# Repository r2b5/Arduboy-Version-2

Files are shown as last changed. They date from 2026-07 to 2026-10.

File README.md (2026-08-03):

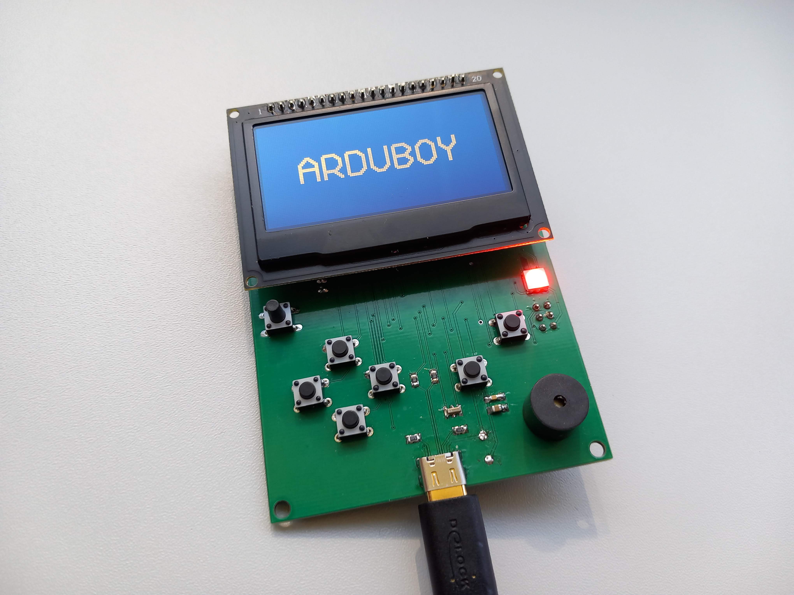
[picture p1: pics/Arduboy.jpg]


# Arduboy Version 2

Arduboy Version 2 is a custom-built handheld game console based on the original **DIY Mini Retro Game Console** by **MaDDy Regal** (Uttar Pradesh, India), published on Instructables.

Unlike the original design, this version integrates the Arduino Nano's **ATmega32U4** microcontroller directly onto a custom PCB. It also features a USB Type-C connector for power and programming, an integrated Li-ion battery charging circuit, and a larger OLED display.

## Hardware

- **Microcontroller:** ATmega32U4-AU
- **Display:** 2.42" 128×64 SPI OLED (Joy-it COM-OLED2.42, SSD1309 controller)
- Integrated Li-ion battery charging circuit MCP73831
- Custom-designed PCB

## Software

- Arduino IDE
- CadSoft Eagle

> **Note:**  
> The game source code is **not my own work**. It consists of example projects that have been adapted to run on this hardware implementation.
>
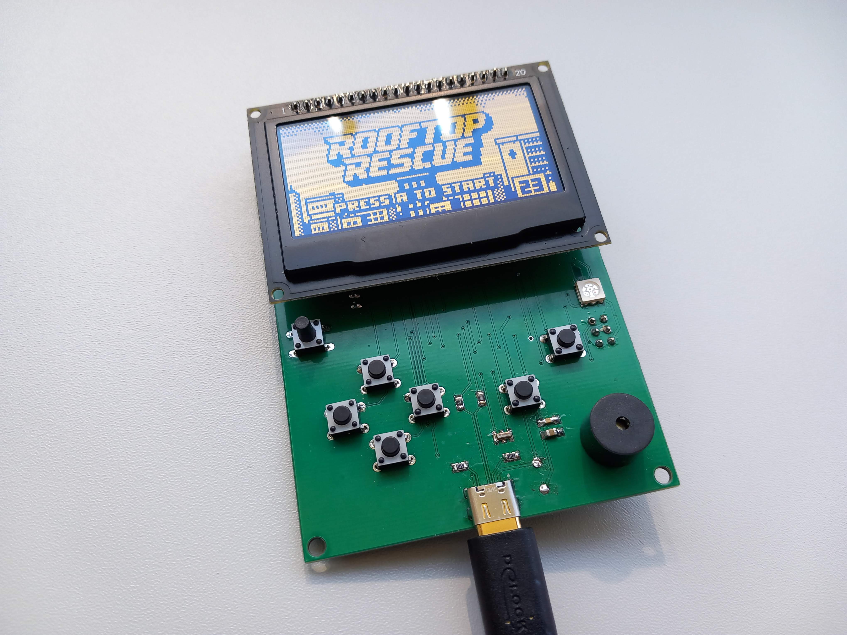
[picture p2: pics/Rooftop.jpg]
> 

## Flashing the Bootloader

An **Arduino Uno** can be used as an ISP programmer to burn the bootloader.

The board provides the standard **6-pin Arduino ISP header**. Before burning the bootloader, select **Arduino Leonardo** as the target board in the Arduino IDE.

| Arduino Uno | Arduboy (Leonardo) |
|---|---|
| D12 | MISO |
| 5V | 5V |
| D13 | SCK |
| D11 | MOSI |
| D10 | RESET |
| GND | GND |

After wiring the programmer, use **Tools → Burn Bootloader** in the Arduino IDE.

## Required Changes to `Arduboy2Core.cpp`

Since this hardware differs from the original Arduboy, a small modification to `Arduboy2Core.cpp` is required for the SSD1309 display to render correctly.

Replace the column and page address initialization with:

```cpp
// Set column address range
0x21, 0x00, COLUMN_ADDRESS_END,

// Set page address range
0x22, 0x00, PAGE_ADDRESS_END
```

## Project Goals

The primary objective of this project is to teach apprentices and interns the fundamentals of microcontroller programming while providing a practical understanding of how embedded electronic systems work.

In addition, the project serves as a foundation for developing more advanced retro gaming consoles and other embedded systems.

## Credits

- Original DIY Mini Retro Game Console concept by **MaDDy Regal**
- Original game source code by **different authors**
- Hardware redesign and PCB development by **Jesus Suarez**

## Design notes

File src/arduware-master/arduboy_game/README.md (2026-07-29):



# ArduWare

A fast-paced Arduboy minigame collection in the style of WarioWare. You'll be thrown into a rapid sequence of short, frantic minigames — each lasting only a few seconds. React fast and do well!

---

## Navigation

| Screen | Controls |
|---|---|
| **Splash screen** | A or B — start |
| **Main menu** | ↑ / ↓ — navigate, A or B — select |
| **Settings** | A — toggle volume, B — toggle game mode, ← — back |

---

## Game Modes

### 🟢 Survival Mode *(default)*

Instead of tracking a score, you start with a **full health bar** displayed at the top of the screen. After each minigame, your health is reduced based on how much of the maximum possible points you *didn't* earn.

- **Miss 0%** of a game's points → lose **0%** health
- **Miss 100%** of a game's points → lose **50%** health (penalties are halved to keep things fair)
- The game ends when your health reaches zero.

Toggle between modes in the **Settings** menu.

### 🔵 Score Mode

The classic mode. Every minigame awards points and the game ends after playing through all the minigames.

---

## Minigames

### 🎯 Buttons!
Arrow icons fall from the top of the screen. Press the matching button before each arrow passes the target line at the bottom.

| Action | Control |
|---|---|
| Match arrow / button | ← ↑ ↓ → A B |

- **10 arrows** per round, **10 pts** each
- Misses reduce your score slightly

---

### 🧠 Repeat! (Simon)
Watch a pattern of 5 buttons flash on screen, then repeat it back in order. One wrong press and the round ends immediately.

| Action | Control |
|---|---|
| Input buttons | ← ↑ ↓ → A B |

- **5 steps**, **10 pts** per correct press
- A single wrong press ends the game — partial credit applies in Survival Mode

---

### 🔦 Chase! (Spotlight)
A smiley face hides in the dark. Move your spotlight to find and stay on top of it. The smiley tries to escape!

| Action | Control |
|---|---|
| Move spotlight | ← ↑ ↓ → |

- Earn **10 pts every 0.5 seconds** while overlapping
- Round lasts **6 seconds**. Max 120 pts.
- RGB LED turns **green** while overlapping, **red** when not

---

### 🌡️ Smash! (Make It Hot)
A thermometer drains constantly. Smash A to fill it up and cross each of the 4 section lines before the timer runs out.

| Action | Control |
|---|---|
| Fill thermometer | A (rapid press) |

- **4 sections**, **10 pts** each = 40 pts max
- Round lasts **6 seconds**

---

### ☕ Catch! (Marshmallow Drop)
6 marshmallows fall from the sky at random intervals and speeds. Move your mug to catch them before they hit the ground!

| Action | Control |
|---|---|
| Move mug | ← → |

- **10 pts** per caught marshmallow, **60 pts** max
- Mug wraps around the edges of the screen

---

### 🦆 Hunt! (Duck Hunt)
4 ducks zip around the screen. Move your crosshair and shoot them all before time runs out. Ducks actively evade you!

| Action | Control |
|---|---|
| Move crosshair | ← ↑ ↓ → |
| Shoot | A or B |

- **10 pts** per duck, **40 pts** max

---

### 🚀 Dodge! (Space Dodge)
You start with 60 points and a field of asteroids. Every collision costs you 10 points — stay alive and keep your score!

| Action | Control |
|---|---|
| Move spaceship | ← ↑ ↓ → |

- Starts at **60 pts**, **-10** per asteroid hit
- Round ends after all asteroids pass

---

### 🔐 Pick! (Lockpick)
You start with 100 points that tick down every second. Rotate the pin to find the hidden sweet spot in the lock cylinder before you run out of points!

| Action | Control |
|---|---|
| Rotate pin | ← → |
| Attempt turn | A |

- Starts at **100 pts**, **-10/second**
- Win before too much time passes to keep a high score

---

### 🎨 Colors! (Color Grid)
A 4×4 grid of squares is shown. The RGB LED tells you the color of the square your cursor is on. Find and tap all 6 squares matching the target color named at the top!

| Action | Control |
|---|---|
| Move cursor | ← ↑ ↓ → |
| Select square | A or B |

- **10 pts** per correct square, **-10 pts** per wrong square
- **6 target squares**, **60 pts** max
- Round lasts **8 seconds**

---

### 🚦 Run! (Red Light, Green Light)
Move across the screen while the light is **green**. Freeze completely when it turns **red** — or you'll be caught!

| Action | Control |
|---|---|
| Move right | A or B (hold) |

- **Win** (reach the finish line) = **100 pts**
- **Fail** (move on red) = partial points based on distance traveled
- Timeout = partial points based on distance
- Round lasts up to **12 seconds**

---

### 🏃 Jump! (Hurdles)
Run automatically and navigate a series of obstacles. Jump over low hurdles, duck under high barriers!

| Action | Control |
|---|---|
| Jump | A or ↑ |
| Duck | B or ↓ |

- **+10 pts every 2 seconds** you survive, **50 pts** max
- One collision ends the round

---

## Credits

Built with [Arduboy2](https://github.com/MLXXXp/Arduboy2) and [ArduboyTones](https://github.com/MLXXXp/ArduboyTones).

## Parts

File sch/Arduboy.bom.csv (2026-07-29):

Qty | Value | Device | Package | Parts | Description | AVAILABILITY | CHECK_PRICES | DESCRIPTION | HEIGHT | MF | MP | MPN | OC_FARNELL | OC_NEWARK | PACKAGE | PRICE | PURCHASE-URL | SNAPEDA_LINK
6 |  | TAC_SWITCHPTH | TACTILE-PTH | S3, S4, S5, S6, S7, S8 | Momentary Switch |  |  |  | 5
1 | 100nF | C0204 | 0204 | C4 | smallest SMD capacitor
1 | 10k | R-EU_M0805 | M0805 | R3 | RESISTOR, European symbol
1 | 10uF | C0204 | 0204 | C3 | smallest SMD capacitor
1 | 16MHz | RESONATOR-MURATACSTCR_G | RESONATOR_MURATA3 | Q1 | Murata ceramic Resonator ceralock" CSTCE series"
1 | 1uF | C0204 | 0204 | C6 | smallest SMD capacitor
2 | 22 | R-EU_M0805 | M0805 | R11, R12 | RESISTOR, European symbol
4 | 220 | R-EU_M0805 | M0805 | R2, R6, R7, R8 | RESISTOR, European symbol
1 | 2k | R-EU_M0805 | M0805 | R1 | RESISTOR, European symbol
2 | 4,7uF | C0204 | 0204 | C2, C5 | smallest SMD capacitor
2 | 5,1k | R-EU_M0805 | M0805 | R4, R5 | RESISTOR, European symbol
1 | 500mA | MF-R055-5,1 | MF-5,1 | F1 | MultiFuse Polyfuse Overcurrent Protectors
1 | ATMEGA32U4-AU | ATMEGA32U4-AU | QFP80P1200X1200X120-44N | U1 | Check availability | In Stock | https://www.snapeda.com/parts/ATMEGA32U4-AU/Microchip+Technology/view-part/?ref=eda | Microcontroller, USB controller 16/32K of ISP flash, TQFP44 industrial, 8-bit | Microchip Technology Inc. ATMEGA32U4-AU |  | Microchip Technology | ATMEGA32U4-AU |  |  |  | TQFP-44 Microchip | None | https://www.snapeda.com/api/url_track_click_mouser/?unipart_id=4247446&manufacturer=Microchip Technology&part_name=ATMEGA32U4-AU&search_term=atmega32u4 | https://www.snapeda.com/parts/ATMEGA32U4-AU/Microchip+Technology/view-part/?ref=snap
1 | B2B-PH-SM4-TB | B2B-PH-SM4-TB | JST_B2B-PH-SM4-TB | J2 | Check availability | In Stock | https://www.snapeda.com/parts/B2B-PH-SM4-TB/JST/view-part/?ref=eda | Connector Header Surface Mount 2 position 0.079 (2.00mm) | 5 | JST | B2B-PH-SM4-TB |  |  |  | NON STANDARD-2 JST | None | https://www.snapeda.com/api/url_track_click_mouser/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 ph 2mm | https://www.snapeda.com/parts/B2B-PH-SM4-TB/JST/view-part/?ref=snap
1 | DTS-6 | DTS-6 | DTS-6 | S2 |  |  |  |  | 7
1 | DX07S016JA1R1500 | DX07S016JA1R1500 | JAE_DX07S016JA1R1500 | J3 | Check availability | In Stock | https://www.snapeda.com/parts/DX07S016JA1R1500/JAE+Electronics/view-part/?ref=eda | USB-C (USB TYPE-C) USB 2.0 Receptacle Connector 24 (16+8 Dummy) Position Surface Mount, Right Angle | Through Hole | 4 | JAE Electronics | DX07S016JA1R1500 |  |  |  | None | None | https://www.snapeda.com/api/url_track_click_mouser/?unipart_id=4551013&manufacturer=JAE Electronics&part_name=DX07S016JA1R1500&search_term=jae, gewinkelt dx usb-steckverbinder buchse usb typ c 1, oberfläche usb 2.0
1 | Ein-Aus | 255SB | 255SB | S1 | SLIDING SWITCH
1 | F/HMB | F/HMB | F/HMB | SG1 | BUZZER Source: Buerklin |  |  |  | 8 |  |  |  | unknown | unknown
1 | F50360 | F50360 | F50360 | LED4 | Full color Z-Power LED RGB P5-II Series
1 | HLMP6 | HLMP6 | HLMP6 | LED1 | LED |  |  |  | 4 | AGILENT TECHNOLOGIES |  | HLMP-6500 | 1652490 | 40K0088
1 | ICSP | PINHD-2X3 | 2X03 | JP1 | PIN HEADER |  |  |  | 5
1 | MCP73831 | MCP73831 | SOT23-5 | U3 | Miniature single cell, fully integrated Li-Ion, Li-polymer charge management controller
1 | SSD1309 | PINHD-1X20 | 1X20 | 128X64 | PIN HEADER |  |  |  | 8
1 | WE-TVS_SOT23-3L | WE-TVS_SOT23-3L | WE-TVS_SOT23-3L | Z1 | TVS Diode Array WE-TVS

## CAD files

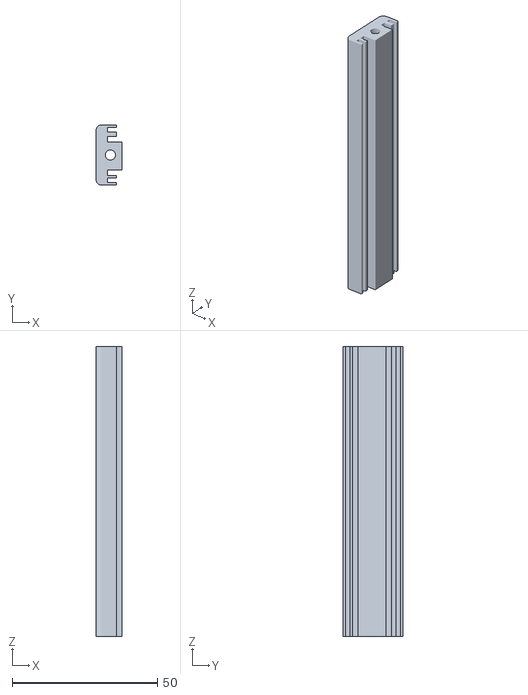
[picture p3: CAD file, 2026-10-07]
cad/Profil.stl
9.00 x 20.8 x 100.0

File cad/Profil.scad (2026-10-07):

// Abmessungen
hoehe    = 20.8;
staerke  = 1;
laenge   = 100;
radius = 2;
loch_d   = 3.5;   // Lochdurchmesser

module e_profil_2d() {
    difference() {

        union() {
            // Langer Schenkel / Rücken
            translate([-1,0])         
            square([2, hoehe]);
            
             hull() {
                translate([-1, radius])
                    circle(r = radius, $fn = 64);

                translate([-1, hoehe - radius])
                    circle(r = radius, $fn = 64);
            }
            

            // Unterer Schenkel
            square([4, 1]);
            
            translate([0, 2.4])
            square([4, 1]); 
            
            // Mittlerer Klotz
            translate([0, 5.3])
            square([6, 9.6]);            
            
 
            translate([0, 16.8])
            square([4, 1.6]); 
            
            // oberer Schenkel
            translate([0, hoehe - 1])
            square([4, 1]);

        }

        // Loch mittig im langen 5-mm-Schenkel
        translate([
            2,
            hoehe / 2
        ])
            circle(d = loch_d, $fn = 64);
    }
}

// E-Kontur inklusive Loch 150 mm extrudieren
linear_extrude(height = laenge)
    e_profil_2d();

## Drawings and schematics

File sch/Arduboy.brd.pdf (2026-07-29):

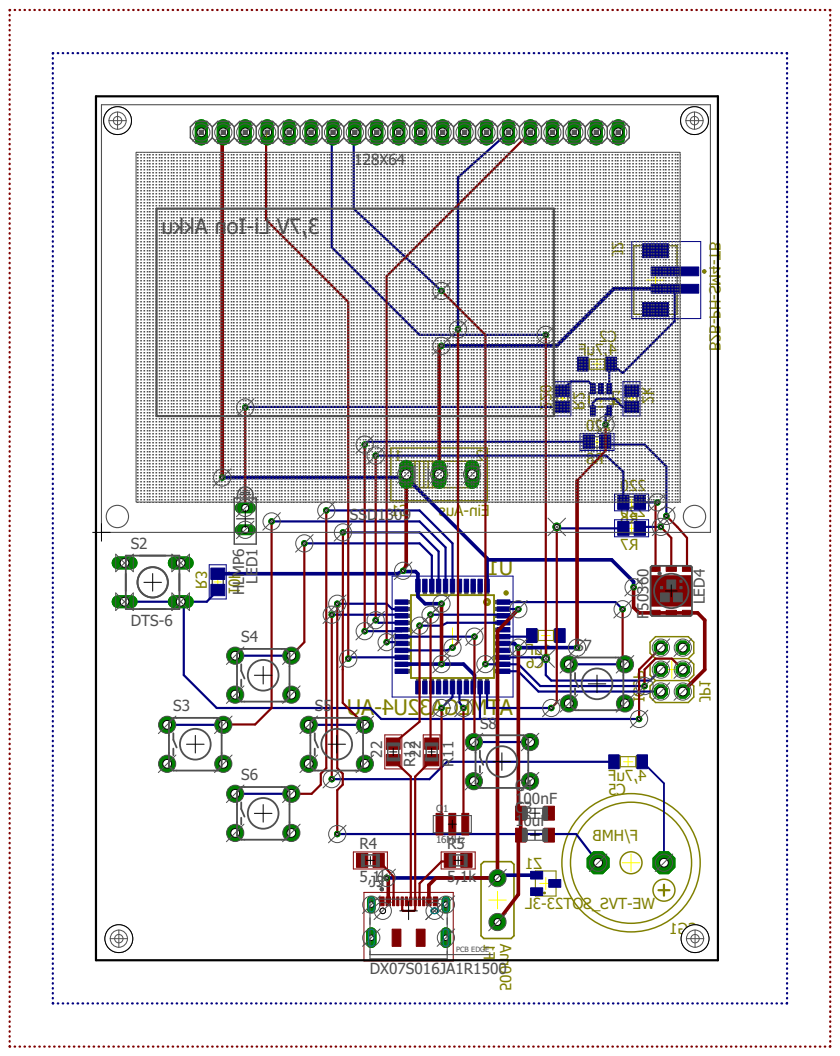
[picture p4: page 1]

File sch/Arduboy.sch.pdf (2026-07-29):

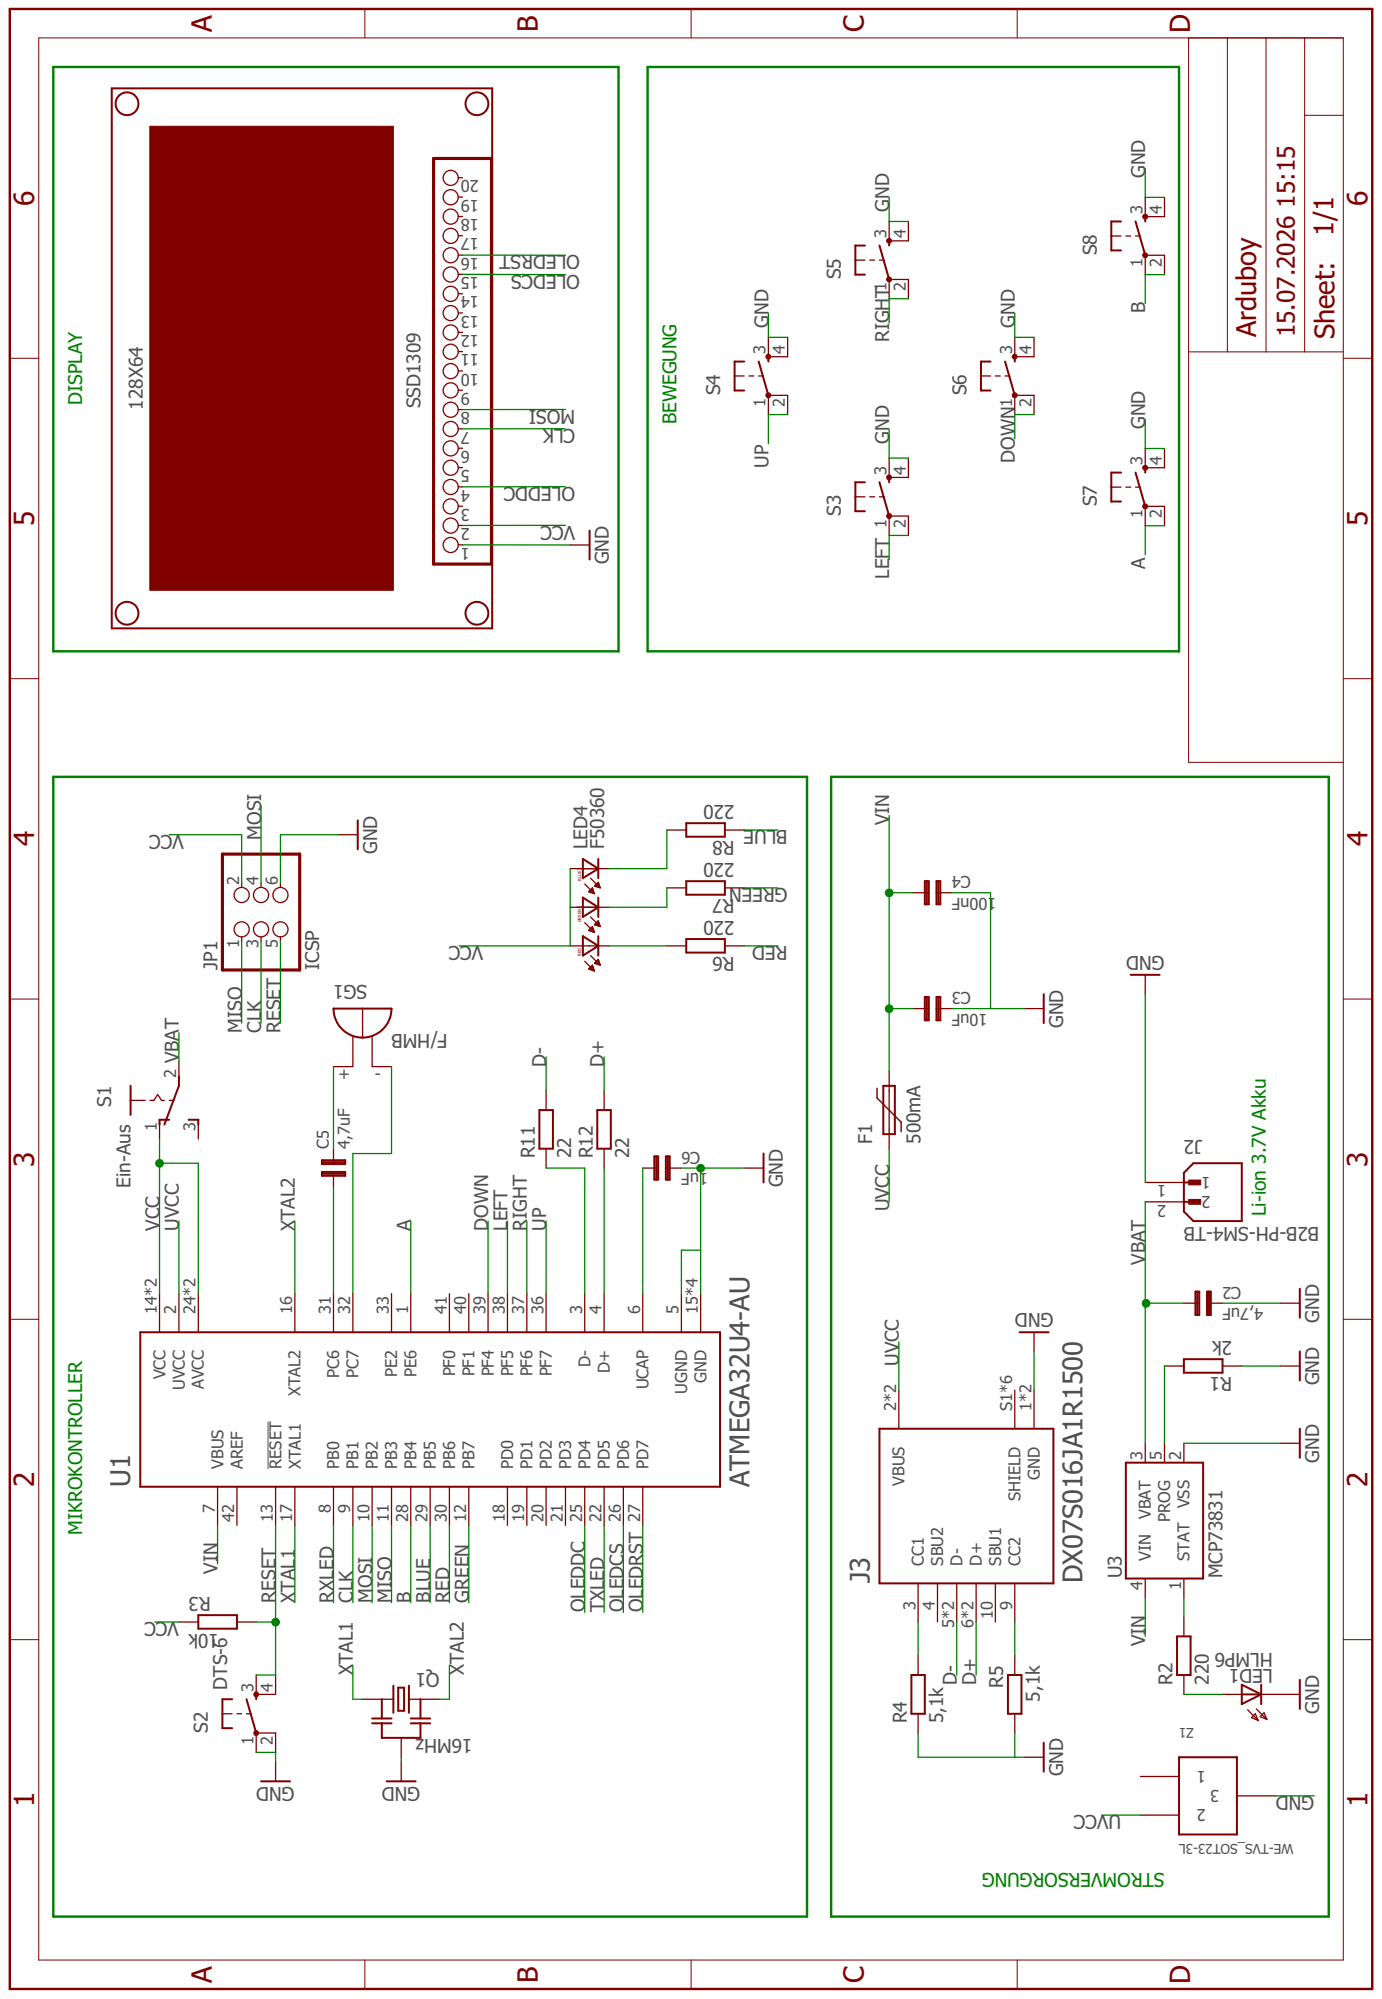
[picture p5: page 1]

RED GREEN BLUE BEWEGUNG

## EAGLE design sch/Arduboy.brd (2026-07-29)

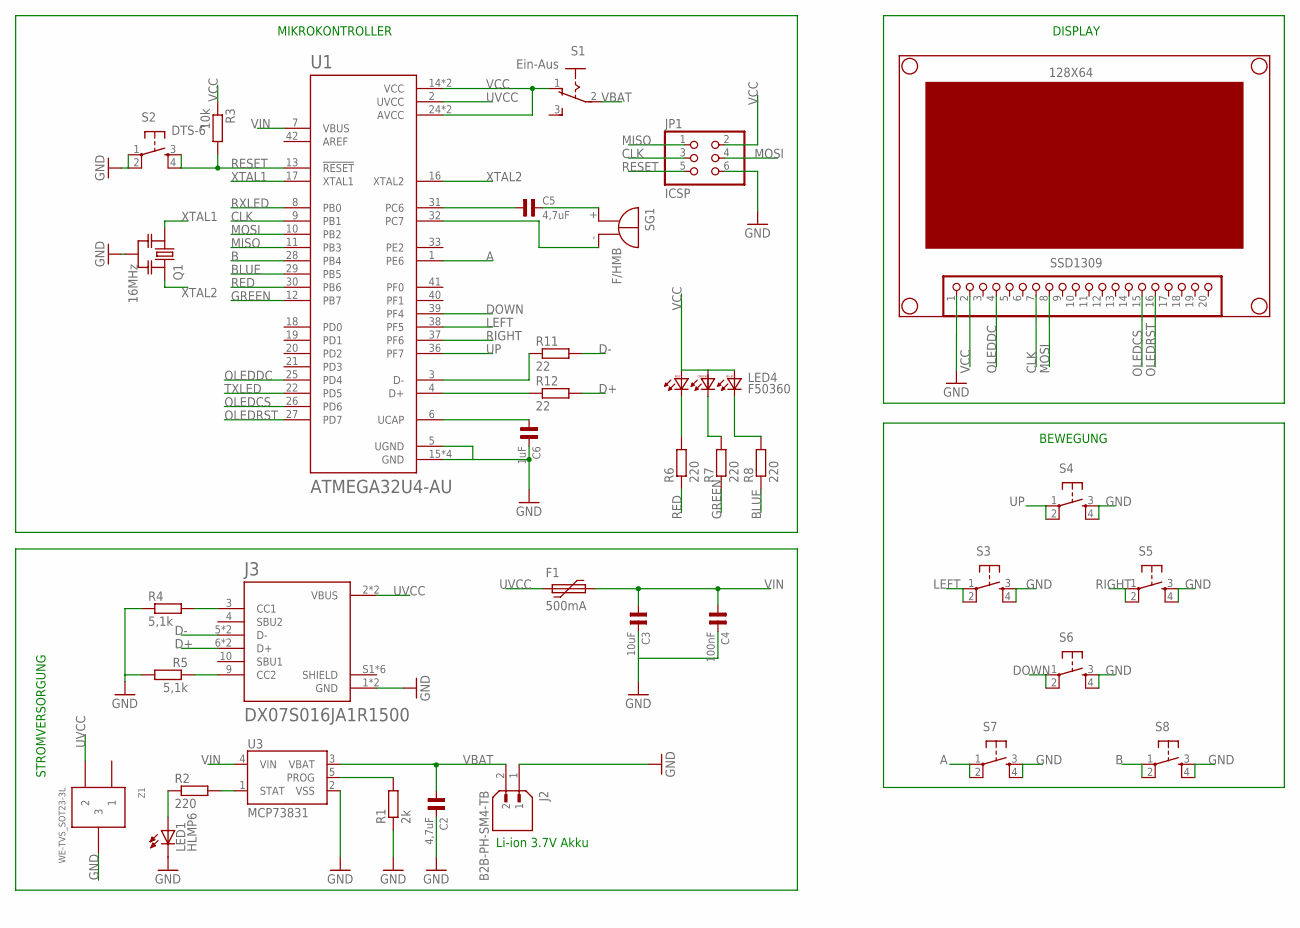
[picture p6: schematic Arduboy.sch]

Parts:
128X64: SSD1309; 1X20
C2, C5: 4,7uF; 0204
C3: 10uF; 0204
C4: 100nF; 0204
C6: 1uF; 0204
F1: 500mA; MF-5,1
J2: B2B-PH-SM4-TB; JST_B2B-PH-SM4-TB
J3: DX07S016JA1R1500; JAE_DX07S016JA1R1500
JP1: ICSP; 2X03
LED1: HLMP6
LED4: F50360
Q1: 16MHz; RESONATOR_MURATA3
R1: 2k; M0805
R2, R6, R7, R8: 220; M0805
R3: 10k; M0805
R4, R5: 5,1k; M0805
R11, R12: 22; M0805
S1: Ein-Aus; 255SB
S2: DTS-6
S3, S4, S5, S6, S7, S8: TAC_SWITCHPTH; TACTILE-PTH
SG1: F/HMB
U1: ATMEGA32U4-AU; QFP80P1200X1200X120-44N
U3: MCP73831; SOT23-5
Z1: WE-TVS_SOT23-3L

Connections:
A: S7.1, S7.2, U1.1 (PE6)
B: S8.1, S8.2, U1.28 (PB4)
BLUE: R8.1, U1.29 (PB5)
CLK: 128X64.7, JP1.3, U1.9 (PB1)
D+: J3.6 (D+), J3.7 (D+), R12.2
D-: J3.5 (D-), J3.8 (D-), R11.2
DOWN: S6.1, S6.2, U1.39 (PF4)
GND: 128X64.1, C2.2, C3.2, C4.2, C6.2, J2.1, J3.1 (GND), J3.12 (GND), JP1.6, LED1.K, Q1.2, R1.1, R4.1, R5.2, S2.1, S2.2, S3.3, S3.4, S4.3, S4.4, S5.3, S5.4, S6.3, S6.4, S7.3, S7.4, S8.3, S8.4, U1.5 (UGND), U1.15 (GND), U1.23 (GND), U1.35 (GND), U1.43 (GND), U3.2 (VSS), Z1.3
GREEN: R7.1, U1.12 (PB7)
LEFT: S3.1, S3.2, U1.38 (PF5)
MISO: JP1.1, U1.11 (PB3)
MOSI: 128X64.8, JP1.4, U1.10 (PB2)
unnamed: R12.1, U1.4 (D+)
unnamed: R11.1, U1.3 (D-)
unnamed: R1.2, U3.5 (PROG)
unnamed: R2.2, U3.1 (STAT)
unnamed: LED1.A, R2.1
unnamed: C5.1, U1.31 (PC6)
unnamed: SG1.-, U1.32 (PC7)
unnamed: C5.2, SG1.+
unnamed: J3.9 (CC2), R5.1
unnamed: LED4.RC, R6.2
unnamed: LED4.GC, R7.2
unnamed: LED4.BC, R8.2
unnamed: C6.1, U1.6 (UCAP)
unnamed: J3.3 (CC1), R4.2
OLEDCS: 128X64.15, U1.26 (PD6)
OLEDDC: 128X64.4, U1.25 (PD4)
OLEDRST: 128X64.16, U1.27 (PD7)
RED: R6.1, U1.30 (PB6)
RESET: JP1.5, R3.2, S2.3, S2.4, U1.13 (!RESET)
RIGHT: S5.1, S5.2, U1.37 (PF6)
RXLED: U1.8 (PB0)
TXLED: U1.22 (PD5)
UP: S4.1, S4.2, U1.36 (PF7)
UVCC: F1.1, J3.2 (VBUS), J3.11 (VBUS), U1.2 (UVCC), Z1.2
VBAT: C2.1, J2.2, S1.2, U3.3 (VBAT)
VCC: 128X64.2, JP1.2, LED4.BA, LED4.GA, LED4.RA, R3.1, S1.1 (O), U1.14 (VCC), U1.24 (AVCC), U1.34 (VCC), U1.44 (AVCC)
VIN: C3.1, C4.1, F1.2, U1.7 (VBUS), U3.4 (VIN)
XTAL1: Q1.1, U1.17 (XTAL1)
XTAL2: Q1.3, U1.16 (XTAL2)

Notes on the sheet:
BEWEGUNG
STROMVERSORGUNG
MIKROKONTROLLER
DISPLAY
Li-ion 3.7V Akku

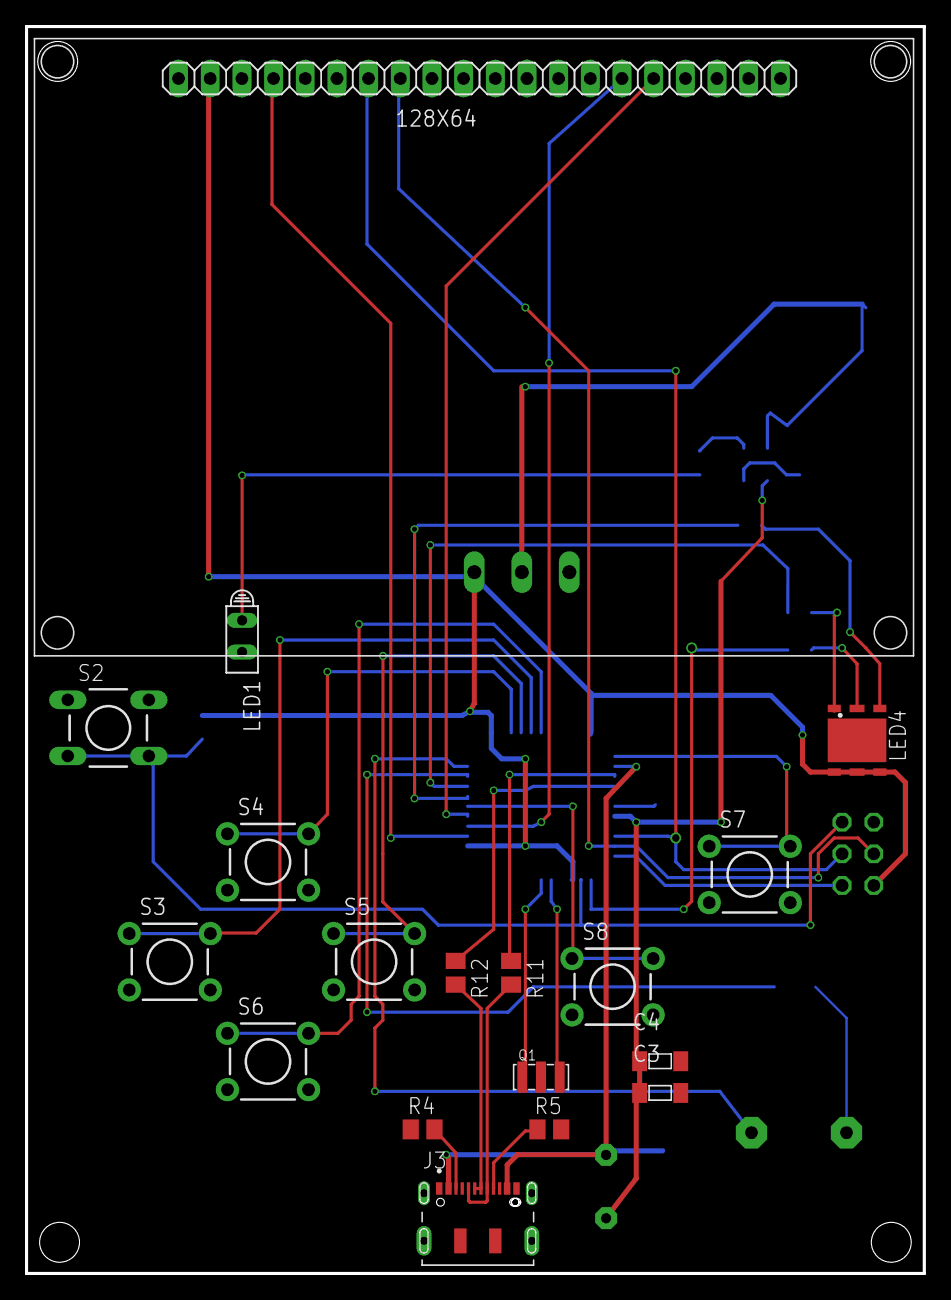
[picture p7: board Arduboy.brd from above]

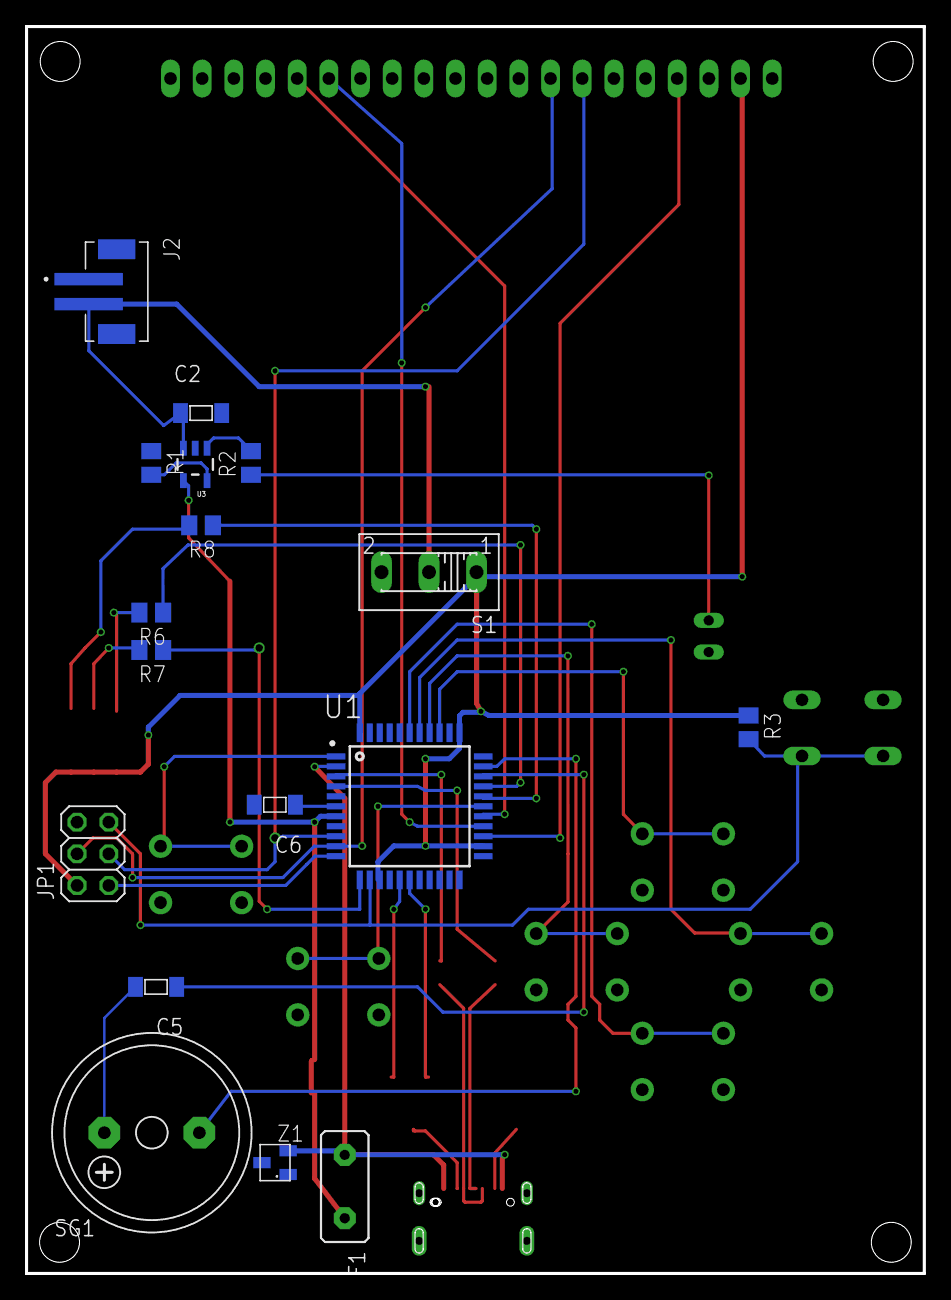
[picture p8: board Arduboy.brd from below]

Board: 2 copper layers, 72.0 x 100.0 mm, 35 parts (17 on the bottom side), 39 nets.

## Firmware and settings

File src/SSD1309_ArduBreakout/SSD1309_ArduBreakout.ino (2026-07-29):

 /*
  Breakout
 Copyright (C) 2011 Sebastian Goscik
 All rights reserved.

 Modifications by Scott Allen 2016, 2018, 2020
 after previous changes by person(s) unknown.

 This library is free software; you can redistribute it and/or
 modify it under the terms of the GNU Lesser General Public
 License as published by the Free Software Foundation; either
 version 2.1 of the License, or (at your option) any later version.
 */

#include <Arduboy2.h>
#include "SerialKeyboard.h"

// block in EEPROM to save high scores
#define EE_FILE 2

// EEPROM space used: 35 bytes (7*(3+2)) starting at
// EEPROM_STORAGE_SPACE_START + (EE_FILE * 35)

Arduboy2 arduboy;
BeepPin1 beep;
SerialKeyboard keyboard;

constexpr uint8_t frameRate = 40; // Frame rate in frames per second

// Tone frequencies. Converted to count values for the beep class
constexpr uint16_t tonePaddle = beep.freq(200); // Ball hits paddle
constexpr uint16_t toneBrick = beep.freq(261); // Ball hits a brick
constexpr uint16_t toneEdge = beep.freq(523); // Ball hits top or sides
constexpr uint16_t toneMiss = beep.freq(175); // Ball misses paddle, lose life
constexpr uint16_t toneInitialsChange = beep.freq(523); // Change initials
constexpr uint16_t toneInitialsMove = beep.freq(1046); // Select initials
// Tone durations
constexpr uint8_t toneTimeBeep = 250 / (1000 / frameRate); // Game (frames)
constexpr uint16_t toneTimeMiss = 500; // Miss paddle (milliseconds)
constexpr uint16_t toneTimeInitials = 80; // Initials entry (milliseconds)


constexpr unsigned int columns = 13; //Columns of bricks
constexpr unsigned int rows = 4;     //Rows of bricks

int dx = -1;        //Initial movement of ball
int dy = -1;        //Initial movement of ball
int xb;           //Ball's starting position
int yb;           //Ball's starting position
boolean released;     //If the ball has been released by the player
boolean paused = false;   //If the game has been paused
byte xPaddle;       //X position of paddle
boolean isHit[rows][columns];   //Array of if bricks are hit or not
boolean bounced=false;  //Used to fix double bounce glitch
byte lives = 3;       //Amount of lives
byte level = 1;       //Current level
unsigned int score=0;   //Score for the game
unsigned int brickCount;  //Amount of bricks hit
boolean pad, pad2, pad3;  //Button press buffer used to stop pause repeating
boolean oldpad, oldpad2, oldpad3;
char text_buffer[16];      //General string buffer
boolean start=false;    //If in menu or in game
boolean initialDraw=false;//If the inital draw has happened
char initials[3];     //Initials used in high score

//Ball Bounds used in collision detection
byte leftBall;
byte rightBall;
byte topBall;
byte bottomBall;

//Brick Bounds used in collision detection
byte leftBrick;
byte rightBrick;
byte topBrick;
byte bottomBrick;

byte tick;

void setup()
{

  arduboy.begin();
  keyboard.begin(115200);  
  beep.begin();
  arduboy.setFrameRate(frameRate);
  arduboy.initRandomSeed();
}

void loop()
{
  keyboard.update();

  // pause render until it's time for the next frame
  if (!(arduboy.nextFrame()))
    return;

  // Handle the timing and stopping of tones
  beep.timer();

  //Title screen loop switches from title screen
  //and high scores until FIRE is pressed
  while (!start)
  {
    start = titleScreen();
    if (!start)
    {
      start = displayHighScores(EE_FILE);
    }
  }

  //Initial level draw
  if (!initialDraw)
  {
    //Clears the screen
    arduboy.clear();
    //Selects Font
    //Draws the new level
    level = 1;
    initialDraw=true;
    newLevel();
    score = 0;
  }

  if (lives>0)
  {
    drawPaddle();

    //Pause game if FIRE pressed
    pad = arduboy.pressed(A_BUTTON) || arduboy.pressed(B_BUTTON);

    if(pad == true && oldpad == false && released)
    {
      oldpad2 = false; //Forces pad loop 2 to run once
      pause();
    }

    oldpad = pad;
    drawBall();

    if(brickCount == rows * columns)
    {
      level++;
      newLevel();
    }
  }
  else
  {
    drawGameOver();
    if (score > 0)
    {
      enterHighScore(EE_FILE);
    }

    arduboy.clear();
    initialDraw=false;
    start=false;
    lives=3;
    newLevel();
  }

  arduboy.display();
}

void movePaddle()
{
  //Move right
  if(xPaddle < WIDTH - 12)
  {
    if (arduboy.pressed(RIGHT_BUTTON))
    {
      xPaddle+=2;
    }
  }

  //Move left
  if(xPaddle > 0)
  {
    if (arduboy.pressed(LEFT_BUTTON))
    {
      xPaddle-=2;
    }
  }
}

void moveBall()
{
  tick++;
  if(released)
  {
    //Move ball
    if (abs(dx)==2)
    {
      xb += dx/2;
      // 2x speed is really 1.5 speed
      if (tick%2==0)
        xb += dx/2;
    }
    else
    {
      xb += dx;
    }
    yb=yb + dy;

    //Set bounds
    leftBall = xb;
    rightBall = xb + 2;
    topBall = yb;
    bottomBall = yb + 2;

    //Bounce off top edge
    if (yb <= 0)
    {
      yb = 2;
      dy = -dy;
      playTone(toneEdge, toneTimeBeep);
    }

    //Lose a life if bottom edge hit
    if (yb >= 64)
    {
      arduboy.drawRect(xPaddle, 63, 11, 1, BLACK);
      xPaddle = 54;
      yb=60;
      released = false;
      lives--;
      playToneTimed(toneMiss, toneTimeMiss);
      if (random(0, 2) == 0)
      {
        dx = 1;
      }
      else
      {
        dx = -1;
      }
    }

    //Bounce off left side
    if (xb <= 0)
    {
      xb = 2;
      dx = -dx;
      playTone(toneEdge, toneTimeBeep);
    }

    //Bounce off right side
    if (xb >= WIDTH - 2)
    {
      xb = WIDTH - 4;
      dx = -dx;
      playTone(toneEdge, toneTimeBeep);
    }

    //Bounce off paddle
    if (xb+1>=xPaddle && xb<=xPaddle+12 && yb+2>=63 && yb<=64)
    {
      dy = -dy;
      dx = ((xb-(xPaddle+6))/3); //Applies spin on the ball
      // prevent straight bounce
      if (dx == 0)
      {
        dx = (random(0, 2) == 1) ? 1 : -1;
      }
      playTone(tonePaddle, toneTimeBeep);
    }

    //Bounce off Bricks
    for (byte row = 0; row < rows; row++)
    {
      for (byte column = 0; column < columns; column++)
      {
        if (!isHit[row][column])
        {
          //Sets Brick bounds
          leftBrick = 10 * column;
          rightBrick = 10 * column + 10;
          topBrick = 6 * row + 1;
          bottomBrick = 6 * row + 7;

          //If A collison has occured
          if (topBall <= bottomBrick && bottomBall >= topBrick &&
              leftBall <= rightBrick && rightBall >= leftBrick)
          {
            Score();
            brickCount++;
            isHit[row][column] = true;
            arduboy.drawRect(10*column, 2+6*row, 8, 4, BLACK);

            //Vertical collision
            if (bottomBall > bottomBrick || topBall < topBrick)
            {
              //Only bounce once each ball move
              if(!bounced)
              {
                dy =- dy;
                yb += dy;
                bounced = true;
                playTone(toneBrick, toneTimeBeep);
              }
            }

            //Hoizontal collision
            if (leftBall < leftBrick || rightBall > rightBrick)
            {
              //Only bounce once brick each ball move
              if(!bounced)
              {
                dx =- dx;
                xb += dx;
                bounced = true;
                playTone(toneBrick, toneTimeBeep);
              }
            }
          }
        }
      }
    }
    //Reset Bounce
    bounced = false;
  }
  else
  {
    //Ball follows paddle
    xb=xPaddle + 5;

    //Release ball if FIRE pressed
    pad3 = arduboy.pressed(A_BUTTON) || arduboy.pressed(B_BUTTON);
    if (pad3 == true && oldpad3 == false)
    {
      released = true;

      //Apply random direction to ball on release
      if (random(0, 2) == 0)
      {
        dx = 1;
      }
      else
      {
        dx = -1;
      }
      //Makes sure the ball heads upwards
      dy = -1;
    }
    oldpad3 = pad3;
  }
}

void drawBall()
{
  arduboy.drawPixel(xb,   yb,   BLACK);
  arduboy.drawPixel(xb+1, yb,   BLACK);
  arduboy.drawPixel(xb,   yb+1, BLACK);
  arduboy.drawPixel(xb+1, yb+1, BLACK);

  moveBall();

  arduboy.drawPixel(xb,   yb,   WHITE);
  arduboy.drawPixel(xb+1, yb,   WHITE);
  arduboy.drawPixel(xb,   yb+1, WHITE);
  arduboy.drawPixel(xb+1, yb+1, WHITE);
}

void drawPaddle()
{
  arduboy.drawRect(xPaddle, 63, 11, 1, BLACK);
  movePaddle();
  arduboy.drawRect(xPaddle, 63, 11, 1, WHITE);
}

void drawGameOver()
{
  arduboy.drawPixel(xb,   yb,   BLACK);
  arduboy.drawPixel(xb+1, yb,   BLACK);
  arduboy.drawPixel(xb,   yb+1, BLACK);
  arduboy.drawPixel(xb+1, yb+1, BLACK);
  arduboy.setCursor(37, 42);
  arduboy.print("Game Over");
  arduboy.setCursor(31, 56);
  arduboy.print("Score: ");
  arduboy.print(score);
  arduboy.display();
  arduboy.delayShort(4000);
}

void pause()
{
  paused = true;
  //Stop tone if playing
  beep.noTone();
  //Draw pause to the screen
  arduboy.setCursor(52, 45);
  arduboy.print("PAUSE");
  arduboy.display();
  while (paused)
  {
    arduboy.delayShort(150);
    //Unpause if FIRE is pressed
    pad2 = arduboy.pressed(A_BUTTON) || arduboy.pressed(B_BUTTON);
    if (pad2 == true && oldpad2 == false && released)
    {
        arduboy.fillRect(52, 45, 30, 11, BLACK);

        paused=false;
    }
    oldpad2 = pad2;
  }
}

void Score()
{
  score += (level*10);
}

void newLevel()
{
  //Undraw paddle
  arduboy.drawRect(xPaddle, 63, 11, 1, BLACK);

  //Undraw ball
  arduboy.drawPixel(xb,   yb,   BLACK);
  arduboy.drawPixel(xb+1, yb,   BLACK);
  arduboy.drawPixel(xb,   yb+1, BLACK);
  arduboy.drawPixel(xb+1, yb+1, BLACK);

  //Alter various variables to reset the game
  xPaddle = 54;
  yb = 60;
  brickCount = 0;
  released = false;

  //Draws new bricks and resets their values
  for (byte row = 0; row < 4; row++)
  {
    for (byte column = 0; column < 13; column++)
    {
      isHit[row][column] = false;
      arduboy.drawRect(10*column, 2+6*row, 8, 4, WHITE);
    }
  }

  if (!initialDraw)
  {
    arduboy.clear();
  }
  else
  {
    arduboy.display();
  }
}

//Used to delay images while reading button input
boolean pollFireButton(int n)
{
  for(int i = 0; i < n; i++)
  {
    arduboy.delayShort(15);
    pad = arduboy.pressed(A_BUTTON) || arduboy.pressed(B_BUTTON);
    if(pad == true && oldpad == false)
    {
      oldpad3 = true; //Forces pad loop 3 to run once
      return true;
    }
    oldpad = pad;
  }
  return false;
}

//Function by nootropic design to display highscores
boolean displayHighScores(byte file)
{
  byte y = 8;
  byte x = 24;
  // Each block of EEPROM has 7 high scores, and each high score entry
  // is 5 bytes long:  3 bytes for initials and two bytes for score.
  int address = file * 7 * 5 + EEPROM_STORAGE_SPACE_START;
  byte hi, lo;
  arduboy.clear();
  arduboy.setCursor(32, 0);
  arduboy.print("HIGH SCORES");
  arduboy.display();

  for(int i = 0; i < 7; i++)
  {
    sprintf(text_buffer, "%2d", i+1);
    arduboy.setCursor(x, y+(i*8));
    arduboy.print(text_buffer);
    arduboy.display();
    hi = EEPROM.read(address + (5*i));
    lo = EEPROM.read(address + (5*i) + 1);

    if ((hi == 0xFF) && (lo == 0xFF))
    {
      score = 0;
    }
    else
    {
      score = (hi << 8) | lo;
    }

    initials[0] = (char)EEPROM.read(address + (5*i) + 2);
    initials[1] = (char)EEPROM.read(address + (5*i) + 3);
    initials[2] = (char)EEPROM.read(address + (5*i) + 4);

    if (score > 0)
    {
      sprintf(text_buffer, "%c%c%c %u", initials[0], initials[1], initials[2], score);
      arduboy.setCursor(x + 24, y + (i*8));
      arduboy.print(text_buffer);
      arduboy.display();
    }
  }
  if (pollFireButton(300))
  {
    return true;
  }
  return false;
  arduboy.display();
}

boolean titleScreen()
{
  //Clears the screen
  arduboy.clear();
  arduboy.setCursor(16, 22);
  arduboy.setTextSize(2);
  arduboy.print("BREAKOUT");
  arduboy.setTextSize(1);
  arduboy.display();
  if (pollFireButton(25))
  {
    return true;
  }

  //Flash "Press FIRE" 5 times
  for(byte i = 0; i < 5; i++)
  {
    //Draws "Press FIRE"
    arduboy.setCursor(31, 53);
    arduboy.print("PRESS FIRE!");
    arduboy.display();

    if (pollFireButton(50))
    {
      return true;
    }

    //Removes "Press FIRE"
    arduboy.setCursor(31, 53);
    arduboy.print("           ");
    arduboy.display();

    if (pollFireButton(25))
    {
      return true;
    }
  }

  return false;
}

//Function by nootropic design to add high scores
void enterInitials()
{
  byte index = 0;

  arduboy.clear();

  initials[0] = ' ';
  initials[1] = ' ';
  initials[2] = ' ';

  while (true)
  {
    arduboy.display();
    arduboy.clear();

    arduboy.setCursor(16, 0);
    arduboy.print("HIGH SCORE");
    sprintf(text_buffer, "%u", score);
    arduboy.setCursor(88, 0);
    arduboy.print(text_buffer);
    arduboy.setCursor(56, 20);
    arduboy.print(initials[0]);
    arduboy.setCursor(64, 20);
    arduboy.print(initials[1]);
    arduboy.setCursor(72, 20);
    arduboy.print(initials[2]);
    for(byte i = 0; i < 3; i++)
    {
      arduboy.drawLine(56 + (i*8), 27, 56 + (i*8) + 6, 27, WHITE);
    }
    arduboy.drawLine(56, 28, 88, 28, BLACK);
    arduboy.drawLine(56 + (index*8), 28, 56 + (index*8) + 6, 28, WHITE);
    arduboy.delayShort(70);

    if (arduboy.pressed(LEFT_BUTTON) || arduboy.pressed(B_BUTTON))
    {
      if (index > 0)
      {
        index--;
        playToneTimed(toneInitialsMove, toneTimeInitials);
      }
    }

    if (arduboy.pressed(RIGHT_BUTTON))
    {
      if (index < 2)
      {
        index++;
        playToneTimed(toneInitialsMove, toneTimeInitials);
      }
    }

    if (arduboy.pressed(UP_BUTTON))
    {
      initials[index]++;
      playToneTimed(toneInitialsChange, toneTimeInitials);
      // A-Z 0-9 :-? !-/ ' '
      if (initials[index] == '0')
      {
        initials[index] = ' ';
      }
      if (initials[index] == '!')
      {
        initials[index] = 'A';
      }
      if (initials[index] == '[')
      {
        initials[index] = '0';
      }
      if (initials[index] == '@')
      {
        initials[index] = '!';
      }
    }

    if (arduboy.pressed(DOWN_BUTTON))
    {
      initials[index]--;
      playToneTimed(toneInitialsChange, toneTimeInitials);
      if (initials[index] == ' ')
      {
        initials[index] = '?';
      }
      if (initials[index] == '/')
      {
        initials[index] = 'Z';
      }
      if (initials[index] == 31)
      {
        initials[index] = '/';
      }
      if (initials[index] == '@')
      {
        initials[index] = ' ';
      }
    }

    if (arduboy.pressed(A_BUTTON))
    {
      playToneTimed(toneInitialsMove, toneTimeInitials);
      if (index < 2)
      {
        index++;
      }
      else
      {
        return;
      }
    }
  }

}

void enterHighScore(byte file)
{
  // Each block of EEPROM has 7 high scores, and each high score entry
  // is 5 bytes long:  3 bytes for initials and two bytes for score.
  int address = file * 7 * 5 + EEPROM_STORAGE_SPACE_START;
  byte hi, lo;
  char tmpInitials[3];
  unsigned int tmpScore = 0;

  // High score processing
  for(byte i = 0; i < 7; i++)
  {
    hi = EEPROM.read(address + (5*i));
    lo = EEPROM.read(address + (5*i) + 1);
    if ((hi == 0xFF) && (lo == 0xFF))
    {
      // The values are uninitialized, so treat this entry
      // as a score of 0.
      tmpScore = 0;
    }
    else
    {
      tmpScore = (hi << 8) | lo;
    }
    if (score > tmpScore)
    {
      enterInitials();
      for(byte j = i; j < 7; j++)
      {
        hi = EEPROM.read(address + (5*j));
        lo = EEPROM.read(address + (5*j) + 1);

        if ((hi == 0xFF) && (lo == 0xFF))
        {
        tmpScore = 0;
        }
        else
        {
          tmpScore = (hi << 8) | lo;
        }

        tmpInitials[0] = (char)EEPROM.read(address + (5*j) + 2);
        tmpInitials[1] = (char)EEPROM.read(address + (5*j) + 3);
        tmpInitials[2] = (char)EEPROM.read(address + (5*j) + 4);

        // write score and initials to current slot
        EEPROM.update(address + (5*j), ((score >> 8) & 0xFF));
        EEPROM.update(address + (5*j) + 1, (score & 0xFF));
        EEPROM.update(address + (5*j) + 2, initials[0]);
        EEPROM.update(address + (5*j) + 3, initials[1]);
        EEPROM.update(address + (5*j) + 4, initials[2]);

        // tmpScore and tmpInitials now hold what we want to
        //write in the next slot.
        score = tmpScore;
        initials[0] = tmpInitials[0];
        initials[1] = tmpInitials[1];
        initials[2] = tmpInitials[2];
      }

      score = 0;
      initials[0] = ' ';
      initials[1] = ' ';
      initials[2] = ' ';

      return;
    }
  }
}

// Play a tone at a frequency coresponding to the specified precomputed count,
// for the specified number of frames.
void playTone(uint16_t count, uint8_t frames)
{
  beep.tone(count, frames);
}

// Play a tone at a frequency coresponding to the specified precomputed count,
// for the specified duration in milliseconds, using a delay.
// Used when beep.timer() isn't being called.
void playToneTimed(uint16_t count, uint16_t duration)
{
  beep.tone(count);
  arduboy.delayShort(duration);
  beep.noTone();
}

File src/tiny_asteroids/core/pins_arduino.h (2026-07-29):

/*
  pins_arduino.h - Pin definition functions for Arduino
  Part of Arduino - http://www.arduino.cc/

  Copyright (c) 2007 David A. Mellis

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
  You should have received a copy of the GNU Lesser General
  Public License along with this library; if not, write to the
  Free Software Foundation, Inc., 59 Temple Place, Suite 330,
  Boston, MA  02111-1307  USA
*/

#ifndef Pins_Arduino_h
#define Pins_Arduino_h

#include <avr/pgmspace.h>

// Workaround for wrong definitions in "iom32u4.h".
// This should be fixed in the AVR toolchain.
#undef UHCON
#undef UHINT
#undef UHIEN
#undef UHADDR
#undef UHFNUM
#undef UHFNUML
#undef UHFNUMH
#undef UHFLEN
#undef UPINRQX
#undef UPINTX
#undef UPNUM
#undef UPRST
#undef UPCONX
#undef UPCFG0X
#undef UPCFG1X
#undef UPSTAX
#undef UPCFG2X
#undef UPIENX
#undef UPDATX
#undef TCCR2A
#undef WGM20
#undef WGM21
#undef COM2B0
#undef COM2B1
#undef COM2A0
#undef COM2A1
#undef TCCR2B
#undef CS20
#undef CS21
#undef CS22
#undef WGM22
#undef FOC2B
#undef FOC2A
#undef TCNT2
#undef TCNT2_0
#undef TCNT2_1
#undef TCNT2_2
#undef TCNT2_3
#undef TCNT2_4
#undef TCNT2_5
#undef TCNT2_6
#undef TCNT2_7
#undef OCR2A
#undef OCR2_0
#undef OCR2_1
#undef OCR2_2
#undef OCR2_3
#undef OCR2_4
#undef OCR2_5
#undef OCR2_6
#undef OCR2_7
#undef OCR2B
#undef OCR2_0
#undef OCR2_1
#undef OCR2_2
#undef OCR2_3
#undef OCR2_4
#undef OCR2_5
#undef OCR2_6
#undef OCR2_7

#define NUM_DIGITAL_PINS  31
#define NUM_ANALOG_INPUTS 12

#define TX_RX_LED_INIT	DDRD |= (1<<5), DDRB |= (1<<0)
#define TXLED0			PORTD |= (1<<5)
#define TXLED1			PORTD &= ~(1<<5)
#define RXLED0			PORTB |= (1<<0)
#define RXLED1			PORTB &= ~(1<<0)

static const uint8_t SDA = 2;
static const uint8_t SCL = 3;
#define LED_BUILTIN 13
#define LED_BUILTIN_RX 17
#define LED_BUILTIN_TX 30

// Map SPI port to 'new' pins D14..D17
static const uint8_t SS   = 17;
static const uint8_t MOSI = 16;
static const uint8_t MISO = 14;
static const uint8_t SCK  = 15;

// Mapping of analog pins as digital I/O
// A6-A11 share with digital pins
static const uint8_t A0 = 18;
static const uint8_t A1 = 19;
static const uint8_t A2 = 20;
static const uint8_t A3 = 21;
static const uint8_t A4 = 22;
static const uint8_t A5 = 23;
static const uint8_t A6 = 24;	// D4
static const uint8_t A7 = 25;	// D6
static const uint8_t A8 = 26;	// D8
static const uint8_t A9 = 27;	// D9
static const uint8_t A10 = 28;	// D10
static const uint8_t A11 = 29;	// D12

#define digitalPinToPCICR(p)    ((((p) >= 8 && (p) <= 11) || ((p) >= 14 && (p) <= 17) || ((p) >= A8 && (p) <= A10)) ? (&PCICR) : ((uint8_t *)0))
#define digitalPinToPCICRbit(p) 0
#define digitalPinToPCMSK(p)    ((((p) >= 8 && (p) <= 11) || ((p) >= 14 && (p) <= 17) || ((p) >= A8 && (p) <= A10)) ? (&PCMSK0) : ((uint8_t *)0))
#define digitalPinToPCMSKbit(p) ( ((p) >= 8 && (p) <= 11) ? (p) - 4 : ((p) == 14 ? 3 : ((p) == 15 ? 1 : ((p) == 16 ? 2 : ((p) == 17 ? 0 : (p - A8 + 4))))))

//	__AVR_ATmega32U4__ has an unusual mapping of pins to channels
extern const uint8_t PROGMEM analog_pin_to_channel_PGM[];
#define analogPinToChannel(P)  ( pgm_read_byte( analog_pin_to_channel_PGM + (P) ) )

#define digitalPinHasPWM(p)         ((p) == 3 || (p) == 5 || (p) == 6 || (p) == 9 || (p) == 10 || (p) == 11 || (p) == 13)

#define digitalPinToInterrupt(p) ((p) == 0 ? 2 : ((p) == 1 ? 3 : ((p) == 2 ? 1 : ((p) == 3 ? 0 : ((p) == 7 ? 4 : NOT_AN_INTERRUPT)))))

#ifdef ARDUINO_MAIN

// On the Arduino board, digital pins are also used
// for the analog output (software PWM).  Analog input
// pins are a separate set.

// ATMEL ATMEGA32U4 / ARDUINO LEONARDO
//
// D0				PD2					RXD1/INT2
// D1				PD3					TXD1/INT3
// D2				PD1		SDA			SDA/INT1
// D3#				PD0		PWM8/SCL	OC0B/SCL/INT0
// D4		A6		PD4					ADC8
// D5#				PC6		???			OC3A/#OC4A
// D6#		A7		PD7		FastPWM		#OC4D/ADC10
// D7				PE6					INT6/AIN0
//
// D8		A8		PB4					ADC11/PCINT4
// D9#		A9		PB5		PWM16		OC1A/#OC4B/ADC12/PCINT5
// D10#		A10		PB6		PWM16		OC1B/0c4B/ADC13/PCINT6
// D11#				PB7		PWM8/16		0C0A/OC1C/#RTS/PCINT7
// D12		A11		PD6					T1/#OC4D/ADC9
// D13#				PC7		PWM10		CLK0/OC4A
//
// A0		D18		PF7					ADC7
// A1		D19		PF6					ADC6
// A2		D20 	PF5					ADC5
// A3		D21 	PF4					ADC4
// A4		D22		PF1					ADC1
// A5		D23 	PF0					ADC0
//
// New pins D14..D17 to map SPI port to digital pins
//
// MISO		D14		PB3					MISO,PCINT3
// SCK		D15		PB1					SCK,PCINT1
// MOSI		D16		PB2					MOSI,PCINT2
// SS		D17		PB0					RXLED,SS/PCINT0
//
// TXLED	D30		PD5					XCK1
// RXLED	D17	    PB0
// HWB				PE2					HWB

// these arrays map port names (e.g. port B) to the
// appropriate addresses for various functions (e.g. reading
// and writing)
const uint16_t PROGMEM port_to_mode_PGM[] = {
	NOT_A_PORT,
	NOT_A_PORT,
	(uint16_t) &DDRB,
	(uint16_t) &DDRC,
	(uint16_t) &DDRD,
	(uint16_t) &DDRE,
	(uint16_t) &DDRF,
};

const uint16_t PROGMEM port_to_output_PGM[] = {
	NOT_A_PORT,
	NOT_A_PORT,
	(uint16_t) &PORTB,
	(uint16_t) &PORTC,
	(uint16_t) &PORTD,
	(uint16_t) &PORTE,
	(uint16_t) &PORTF,
};
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

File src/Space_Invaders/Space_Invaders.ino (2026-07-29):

#include <Arduboy2.h>
Arduboy2 arduboy;

// DISPLAY SETTINGS

#define SCREEN_WIDTH 128
#define SCREEN_HEIGHT 64

// Input settings
#define FIRE_BUT 7
#define RIGHT_BUT A1
#define LEFT_BUT A2

// Alien Settings
#define NUM_ALIEN_COLUMNS 7
#define NUM_ALIEN_ROWS 3
#define X_START_OFFSET 6
#define SPACE_BETWEEN_ALIEN_COLUMNS 5
#define LARGEST_ALIEN_WIDTH 11
#define SPACE_BETWEEN_ROWS 9
#define INVADERS_DROP_BY 4            // pixel amount that invaders move down by
#define INVADERS_SPEED 20             // speed of movement, lower=faster.
#define INVADER_HEIGHT 8

// Player settingsc
#define TANKGFX_WIDTH 13
#define TANKGFX_HEIGHT 8
#define PLAYER_X_MOVE_AMOUNT 1
#define PLAYER_Y_START 56
#define PLAYER_X_START 0

#define MISSILE_HEIGHT 4
#define MISSILE_WIDTH 1
#define MISSILE_SPEED 1

// Status of a game object constants
#define ACTIVE 0
#define DESTROYED 2

// graphics
// aliens

const unsigned char InvaderTopGfx [] PROGMEM = {
  0x98, 0x5c, 0xb6, 0x5f, 0x5f, 0xb6, 0x5c, 0x98
};

const unsigned char InvaderTopGfx2 [] PROGMEM = {
  0x58, 0xbc, 0x16, 0x1f, 0x1f, 0x16, 0xbc, 0x58
};

const unsigned char PROGMEM InvaderMiddleGfx [] =
{
  0x1e, 0xb8, 0x7d, 0x36, 0x3c, 0x3c, 0x3c, 0x36, 0x7d, 0xb8, 0x1e
};

const unsigned char PROGMEM InvaderMiddleGfx2 [] = {
  0x78, 0x18, 0x7d, 0xb6, 0xbc, 0x3c, 0xbc, 0xb6, 0x7d, 0x18, 0x78
};

const unsigned char PROGMEM InvaderBottomGfx [] = {
  0x1c, 0x5e, 0xfe, 0xb6, 0x37, 0x5f, 0x5f, 0x37, 0xb6, 0xfe, 0x5e, 0x1c
};

const unsigned char PROGMEM InvaderBottomGfx2 [] = {
  0x9c, 0xde, 0x7e, 0x36, 0x37, 0x5f, 0x5f, 0x37, 0x36, 0x7e, 0xde, 0x9c
};

// Player grafix
const unsigned char PROGMEM TankGfx [] = {
  0xf0, 0xf8, 0xf8, 0xf8, 0xf8, 0xfe, 0xff, 0xfe, 0xf8, 0xf8, 0xf8, 0xf8, 0xf0
};

static const unsigned char PROGMEM MissileGfx [] = {
  0x0f, 0x00, 0x00, 0x00, 0x00, 0x00, 0x00, 0x00

};


// Game structures

struct GameObjectStruct  {
  // base object which most other objects will include
  signed int X;
  signed int Y;
  unsigned char Status;  //0 active, 1 exploding, 2 destroyed
};

struct AlienStruct  {
  GameObjectStruct Ord;
};

struct PlayerStruct  {
  GameObjectStruct Ord;
};

//alien global vars
//The array of aliens across the screen
AlienStruct  Alien[NUM_ALIEN_COLUMNS][NUM_ALIEN_ROWS];


// widths of aliens
// as aliens are the same type per row we do not need to store their graphic width per alien in the structure above
// that would take a byte per alien rather than just three entries here, 1 per row, saving significnt memory
byte AlienWidth[] = {8, 11, 12}; // top, middle ,bottom widths


char AlienXMoveAmount = 1; // norm is 2 , this is pixel movement in X
signed char InvadersMoveCounter;            // counts down, when 0 move invaders, set according to how many aliens on screen
bool AnimationFrame = false; // two frames of animation, if true show one if false show the other


// Player global variables
PlayerStruct Player;
GameObjectStruct Missile;


void setup()
{
  arduboy.begin();
  arduboy.setFrameRate(60);

  InitAliens(0);
  InitPlayer();

  pinMode(RIGHT_BUT, INPUT_PULLUP);
  pinMode(LEFT_BUT, INPUT_PULLUP);
  pinMode(FIRE_BUT, INPUT_PULLUP);

}

void loop()
{
  if (!arduboy.nextFrame()) {
    return;
  }

  Physics();
  UpdateDisplay();

}

void Physics()  {
  AlienControl();
  PlayerControl();
  MissileControl();
  CheckCollisions();
}


void PlayerControl()  {
  // user input checks
  if ((digitalRead(RIGHT_BUT) == 0) & (Player.Ord.X + TANKGFX_WIDTH < SCREEN_WIDTH))
    Player.Ord.X += PLAYER_X_MOVE_AMOUNT;
  if ((digitalRead(LEFT_BUT) == 0) & (Player.Ord.X > 0))
    Player.Ord.X -= PLAYER_X_MOVE_AMOUNT;
  if ((digitalRead(FIRE_BUT) == 0) & (Missile.Status != ACTIVE))
  {
    Missile.X = Player.Ord.X + (6); // offset missile so its in the mideel of the tank
    Missile.Y = PLAYER_Y_START;
    Missile.Status = ACTIVE;

  }
}

void MissileControl()
{
  if (Missile.Status == ACTIVE)
  {
    Missile.Y -= MISSILE_SPEED;
    if (Missile.Y + MISSILE_HEIGHT < 0)  // If off top of screen destroy so can be used again
      Missile.Status = DESTROYED;
  }
}


void AlienControl()
{
  if ((InvadersMoveCounter--) < 0)
  {
    bool Dropped = false;
    if ((RightMostPos() + AlienXMoveAmount >= SCREEN_WIDTH) | (LeftMostPos() + AlienXMoveAmount < 0)) // at edge of screen
    {
      AlienXMoveAmount = -AlienXMoveAmount;             // reverse direction
      Dropped = true;                                   // and indicate we are dropping
    }
    // update the alien postions
    for (int Across = 0; Across < NUM_ALIEN_COLUMNS; Across++)
    {
      for (int Down = 0; Down < 3; Down++)
      {
        if (Alien[Across][Down].Ord.Status == ACTIVE)
        {
          if (Dropped == false)
            Alien[Across][Down].Ord.X += AlienXMoveAmount;
          else
            Alien[Across][Down].Ord.Y += INVADERS_DROP_BY;
        }
      }
    }
    InvadersMoveCounter = INVADERS_SPEED;
    AnimationFrame = !AnimationFrame; ///swap to other frame
  }
}


void CheckCollisions()
{
  MissileAndAlienCollisions();
}


void MissileAndAlienCollisions()
{
  for (int across = 0; across < NUM_ALIEN_COLUMNS; across++)
  {
    for (int down = 0; down < NUM_ALIEN_ROWS; down++)
    {
      if (Alien[across][down].Ord.Status == ACTIVE)
      {
        if (Missile.Status == ACTIVE)
        {
          if (Collision(Missile, MISSILE_WIDTH, MISSILE_HEIGHT, Alien[across][down].Ord, AlienWidth[down], INVADER_HEIGHT))
          {
            // missile hit
            Alien[across][down].Ord.Status = DESTROYED;
            Missile.Status = DESTROYED;
          }
        }
      }
    }
  }
}

bool Collision(GameObjectStruct Obj1, unsigned char Width1, unsigned char Height1, GameObjectStruct Obj2, unsigned char Width2, unsigned char Height2)
{
  return ((Obj1.X + Width1 > Obj2.X) & (Obj1.X < Obj2.X + Width2) & (Obj1.Y + Height1 > Obj2.Y) & (Obj1.Y < Obj2.Y + Height2));
}

int RightMostPos()  {
  //returns x pos of right most alien
  int Across = NUM_ALIEN_COLUMNS - 1;
  int Down;
  int Largest = 0;
  int RightPos;
  while (Across >= 0) {
    Down = 0;
    while (Down < NUM_ALIEN_ROWS) {
      if (Alien[Across][Down].Ord.Status == ACTIVE)
      {
        // different aliens have different widths, add to x pos to get rightpos
        RightPos = Alien[Across][Down].Ord.X + AlienWidth[Down];
        if (RightPos > Largest)
          Largest = RightPos;
      }
      Down++;
    }
    if (Largest > 0) // we have found largest for this coloum
      return Largest;
    Across--;
  }
  return 0;  // should never get this far
}
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

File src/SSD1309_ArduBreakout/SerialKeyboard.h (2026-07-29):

#ifndef SERIALKEYBOARD_H
#define SERIALKEYBOARD_H

#include <Arduino.h>

#define SK_UP_BUTTON        7
#define SK_DOWN_BUTTON      6
#define SK_LEFT_BUTTON      9
#define SK_RIGHT_BUTTON     5
#define SK_A_BUTTON         8
#define SK_B_BUTTON         4



class SerialKeyboard {
private:
    char lastKey = 0;

public:

    void begin(unsigned long baud = 115200) {

        Serial.begin(baud);
        pinMode(SK_UP_BUTTON, OUTPUT);  //UP
        pinMode(SK_DOWN_BUTTON, OUTPUT);  //DOWN
        pinMode(SK_LEFT_BUTTON, OUTPUT);  //LEFT
        pinMode(SK_RIGHT_BUTTON, OUTPUT);  //RIGT

        pinMode(SK_A_BUTTON, OUTPUT);  //A
        pinMode(SK_B_BUTTON, OUTPUT);  //B

    }

    void update() {

/*
    digitalWrite(SK_UP_BUTTON,HIGH);
    digitalWrite(SK_DOWN_BUTTON,HIGH);
    digitalWrite(SK_LEFT_BUTTON,HIGH);
    digitalWrite(SK_RIGHT_BUTTON,HIGH);
    digitalWrite(SK_A_BUTTON,HIGH);
    digitalWrite(SK_B_BUTTON,HIGH);
*/

    if (Serial.available() > 0) {
        lastKey = Serial.read();
        /*switch(lastKey){
           case 'w': digitalWrite(SK_UP_BUTTON,LOW);break;
           case 's': digitalWrite(SK_DOWN_BUTTON,LOW);break;
           case 'a': digitalWrite(SK_LEFT_BUTTON,LOW);break;
           case 'd': digitalWrite(SK_RIGHT_BUTTON,LOW);break;
           case 'n': digitalWrite(SK_A_BUTTON,LOW);break;
           case 'm': digitalWrite(SK_B_BUTTON,LOW);break;
        }*/
        Serial.print(lastKey);

        } else {
            lastKey = 0;
        }
    }


};

#endif

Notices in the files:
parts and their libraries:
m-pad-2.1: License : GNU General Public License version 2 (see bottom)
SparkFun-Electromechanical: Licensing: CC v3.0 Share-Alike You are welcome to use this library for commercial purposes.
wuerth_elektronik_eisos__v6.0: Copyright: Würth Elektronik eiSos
